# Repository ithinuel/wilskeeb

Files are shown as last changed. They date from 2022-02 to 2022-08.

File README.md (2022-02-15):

# Wil's Keyboard

This project implements a split keyboard based on the [Redox](https://github.com/mattdibi/redox-keyboard)
PCB but powered by a [SparkFun Pro Micro - RP2040](https://www.sparkfun.com/products/18288).

It features:

- Automatic main-secondary detection (either side can be connected to usb)
- Automatic chirality detection allowing the same binary to run on both sides.
- A virtual serial port to a simple CLI to help with debugging & update.
- 128x64 (SH1107 based) Oled display support

Extra optional features are also available:

- RGB Led strip

The communication between main & secondary is done through an I²C interface.

## Firmware deployment

On a fresh RP2040 enter into bootload by maintaining the boot button pressed while pressing reset.
Then run `cargo run --release` to compile and flash the firmware.

Refer to defmt documentation for available logging parameters.

I used the following command to update the firmware after the case is assembled and the buttons are
no-longer accessible.

```sh
DEFMT_BBQ_BUFFER_SIZE=4096 DEFMT_LOG=trace cargo build --release && echo -n u >> [your-uart] && sleep 5 && elf2uf2-rs -d target/thumbv6m-none-eabi/release/wilskeeb
```

## Layout

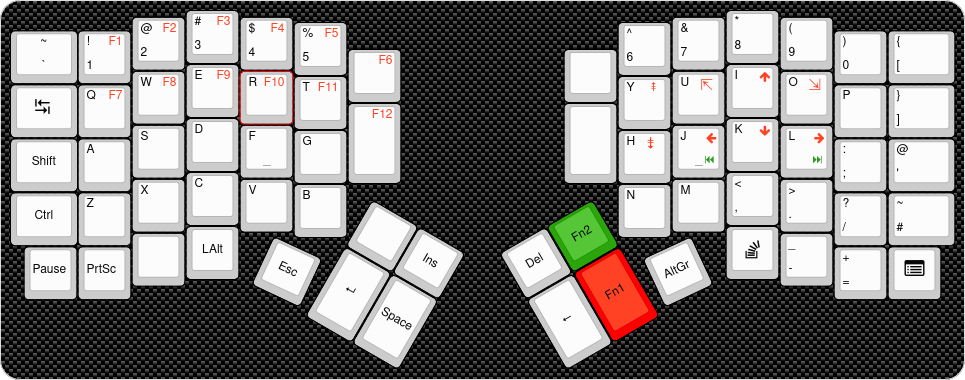
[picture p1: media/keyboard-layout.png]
Keyboard layout
[](http://www.keyboard-layout-editor.com/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(%0A9%3B&@_y:-0.905&x:5.25&t=%23000000%0A%0A%23ff0000%3B&=%25%0A5%0AF5&_x:5&t=%23000000%3B&=%5E%0A6%3B&@_y:-0.845&a:5&w:1.25%3B&=~%0A%60&_t=%23000000%0A%0A%23ff0000&a:4%3B&=!%0A1%0AF1&_x:13&t=%23000000%3B&=)%0A0&_w:1.25%3B&=%7B%0A%5B%3B&@_y:-0.655&x:6.25&t=%23000000%0A%0A%23ff0000%3B&=%0A%0AF6&_x:3&t=%23000000&a:7%3B&=%3B&@_y:-0.72&x:3.25&t=%23000000%0A%0A%23ff0000&a:4%3B&=E%0A%0AF9&_x:9%3B&=I%0A%0A%3Ci%20class%2F='fa%20fa-arrow-up'%3E%3C%2F%2Fi%3E%3B&@_y:-0.875&x:2.25%3B&=W%0A%0AF8&_x:1%3B&=R%0A%0AF10&_x:7&fa@:0&:0&:5%3B%3B&=U%0A%0A%3Ci%20class%2F='kb%20kb-Arrows-Top-2'%3E%3C%2F%2Fi%3E&_x:1%3B&=O%0A%0A%3Ci%20class%2F='kb%20kb-Arrows-Bottom-2'%3E%3C%2F%2Fi%3E%3B&@_y:-0.905&x:5.25&f:3%3B&=T%0A%0AF11&_x:5&f:3%3B&=Y%0A%0A%3Ci%20class%2F='kb%20kb-Unicode-Page-Up-3'%3E%3C%2F%2Fi%3E%3B&@_y:-0.845&t=%23000000&a:7&fa@:7%3B&w:1.25%3B&=%3Ci%20class%2F='kb%20kb-Line-Start-End'%3E%3C%2F%2Fi%3E&_t=%23000000%0A%0A%23ff0000&a:4&f:3%3B&=Q%0A%0AF7%3B&@_y:-1&x:15.25&t=%23000000&f:3%3B&=P&_f:3&w:1.25%3B&=%7D%0A%5D%3B&@_y:-0.655&x:6.25&t=%23000000%0A%0A%23ff0000&h:1.5%3B&=%0A%0AF12&_x:3&t=%23000000&a:7&h:1.5%3B&=%3B&@_y:-0.72&x:3.25&a:4&f:3%3B&=D%3B&@_y:-1&x:13.25&t=%23000000%0A%0A%23ff0000&f:3%3B&=K%0A%0A%3Ci%20class%2F='fa%20fa-arrow-down'%3E%3C%2F%2Fi%3E%3B&@_y:-0.875&x:2.25&t=%23000000&f:3%3B&=S&_x:1&f:3&n:true%3B&=F&_x:7&t=%23000000%0A%0A%23ff0000%0A%23008000&f:3&n:true%3B&=J%0A%0A%3Ci%20class%2F='fa%20fa-arrow-left'%3E%3C%2F%2Fi%3E%0A%3Ci%20class%2F='kb%20kb-Multimedia-Rewind-Start'%3E%3C%2F%2Fi%3E&_x:1&f:3%3B&=L%0A%0A%3Ci%20class%2F='fa%20fa-arrow-right'%3E%3C%2F%2Fi%3E%0A%3Ci%20class%2F='kb%20kb-Multimedia-FastForward-End'%3E%3C%2F%2Fi%3E%3B&@_y:-0.9049999999999998&x:5.25&t=%23000000&f:3%3B&=G&_x:5&t=%23000000%0A%0A%23ff0000&fa@:0&:0&:5%3B%3B&=H%0A%0A%3Ci%20class%2F='kb%20kb-Unicode-Page-Down-3'%3E%3C%2F%2Fi%3E%3B&@_y:-0.8450000000000002&t=%23000000&a:7&w:1.25%3B&=Shift&_a:4%3B&=A&_x:13%3B&=%2F:%0A%2F%3B&_w:1.25%3B&=%2F@%0A'%3B&@_y:-0.375&x:3.25%3B&=C&_x:9%3B&=%3C%0A,%3B&@_y:-0.875&x:2.25%3B&=X&_x:1%3B&=V&_x:7%3B&=M&_x:1%3B&=%3E%0A.%3B&@_y:-0.9049999999999998&x:5.25%3B&=B&_x:5%3B&=N%3B&@_y:-0.8450000000000006&a:7&w:1.25%3B&=Ctrl&_a:4%3B&=Z&_x:13%3B&=%3F%0A%2F%2F&_w:1.25%3B&=~%0A%23%3B&@_y:-0.375&x:3.25&a:7%3B&=LAlt&_x:9&fa@:6%3B%3B&=%3Ci%20class%2F='fa%20fa-stack-overflow'%3E%3C%2F%2Fi%3E%3B&@_y:-0.875&x:2.25%3B&=&_x:11&a:4&f:3%3B&=%2F_%0A-%3B&@_y:-0.75&x:0.25&a:6&f:3%3B&=Pause&_f:3%3B&=PrtSc&_x:13&a:4&f:3%3B&=+%0A%2F=&_a:7&fa@:7%3B%3B&=%3Ci%20class%2F='fa%20fa-list-alt'%3E%3C%2F%2Fi%3E%3B&@_r:25&rx:5.135&ry:4.845&y:-0.5&x:-0.5&f:3%3B&=Esc%3B&@_r:30&rx:7.068&ry:4.875&y:-1&x:-1%3B&=&_f:3%3B&=Ins%3B&@_x:-1&f:3&h:1.5%3B&=%3Ci%20class%2F='kb%20kb-Return-2'%3E%3C%2F%2Fi%3E&_f:3&h:1.5%3B&=Space%3B&@_r:-30&rx:10.432&y:-1&x:-1&f:3%3B&=Del&_c=%232aa50a&f:3%3B&=Fn2%3B&@_x:-1&c=%23cccccc&f:3&h:1.5%3B&=%3Ci%20class%2F='kb%20kb-Arrows-Left'%3E%3C%2F%2Fi%3E&_c=%23ff0000&f:3&h:1.5%3B&=Fn1%3B&@_r:-25&rx:12.365&ry:4.845&y:-0.5&x:-0.5&c=%23cccccc&f:3%3B&=AltGr)

## Licenses

The hardware design files present in this repository under the `pcb` and `case` directories are
distributed under the [CERN OHL S v2 License](./cern_ohl_s_v2.txt).

```text
Copyright Wilfried Chauveau 2022.

This source describes Open Hardware and is licensed under the CERN-OHL-S v2.
You may redistribute and modify this source and make products using it under
the terms of the CERN-OHL-S v2 (https://ohwr.org/cern_ohl_s_v2.txt).

This source is distributed WITHOUT ANY EXPRESS OR IMPLIED WARRANTY, INCLUDING
OF MERCHANTABILITY, SATISFACTORY QUALITY AND FITNESS FOR A PARTICULAR PURPOSE.
Please see the CERN-OHL-S v2 for applicable conditions.

Source location: https://github.com/ithinuel/wilskeeb.git

As per CERN-OHL-S v2 section 4, should You produce hardware based on this source,
You must where practicable maintain the Source Location visible on the external
case of the Gizmo or other products you make using this source.
```

The sources available under the `firmware` directory are distributed under the
[Apache 2](./Apache-2.0.txt) license.

```text
Copyright 2022 Wilfried Chauveau

Licensed under the Apache License, Version 2.0 (the "License");
you may not use this file except in compliance with the License.
You may obtain a copy of the License at

    http://www.apache.org/licenses/LICENSE-2.0

Unless required by applicable law or agreed to in writing, software
distributed under the License is distributed on an "AS IS" BASIS,
WITHOUT WARRANTIES OR CONDITIONS OF ANY KIND, either express or implied.
See the License for the specific language governing permissions and
limitations under the License.
```

## Extra resources

- The 3D model for the Audio jack is available at : [Kicad-packages3D − MR#495](https://gitlab.com/kicad/libraries/kicad-packages3D/-/merge_requests/495)
- The PCB design for the OLED display can be found at : [Github − Adafruit OLED FeatherWing PCB](https://github.com/adafruit/Adafruit-OLED-FeatherWing-PCB.git)
- The PCB design for the Pro Micro RP2040 can be found at : [Github − SparkFun Pro Micro RP2040](https://github.com/sparkfun/SparkFun_Pro_Micro-RP2040.git)

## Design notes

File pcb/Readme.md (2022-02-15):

# PCD Design

## Option considered

- on board per key rgb LED using WS2812-2020  
  Those RGB LED draw up to 20mA and there would be 35 of them. This plus the rest of the system would
  exceed the capacity of the USB port.

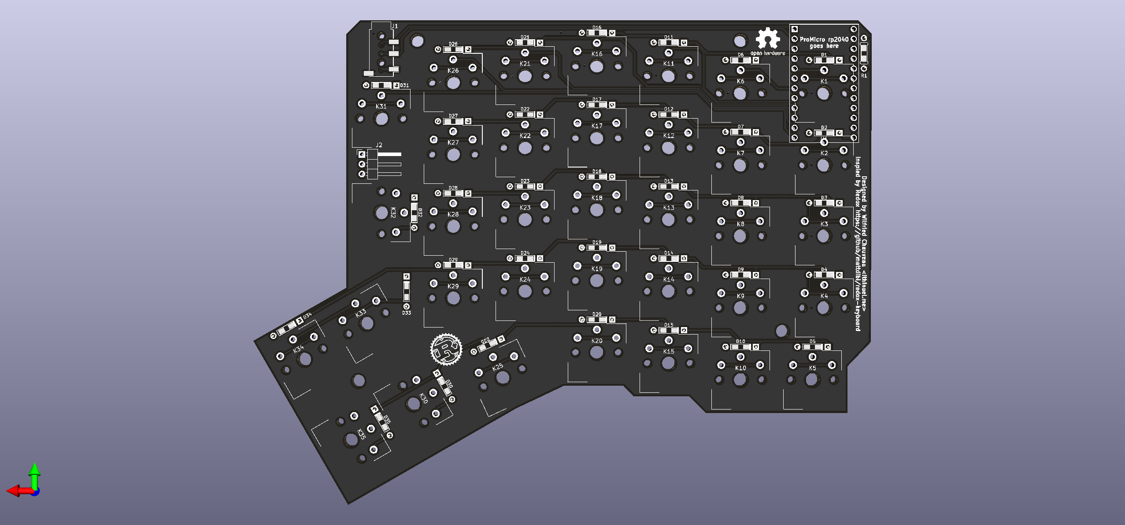
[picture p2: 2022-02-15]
media/wilskeeb_6.png

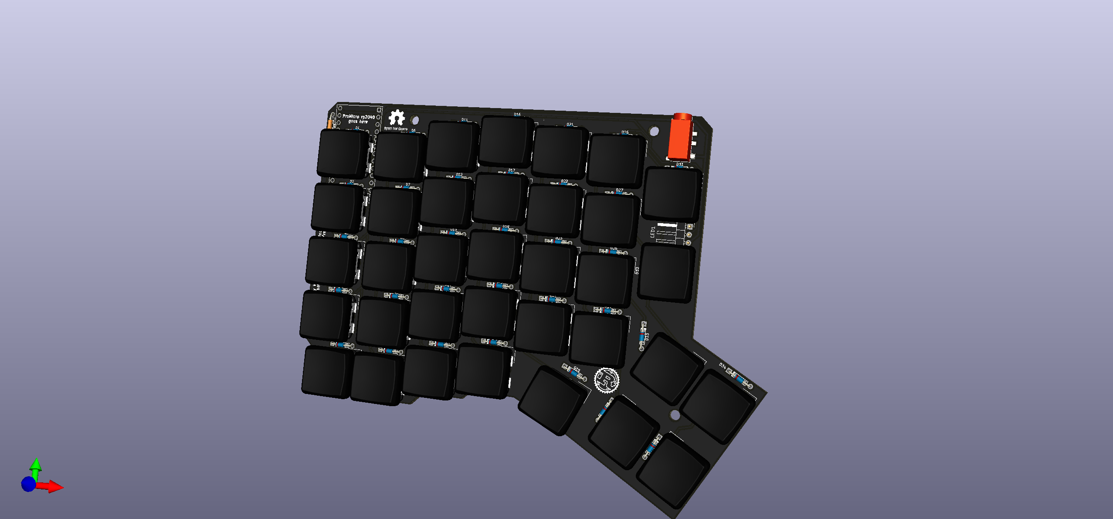
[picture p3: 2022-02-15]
media/wilskeeb_1.png

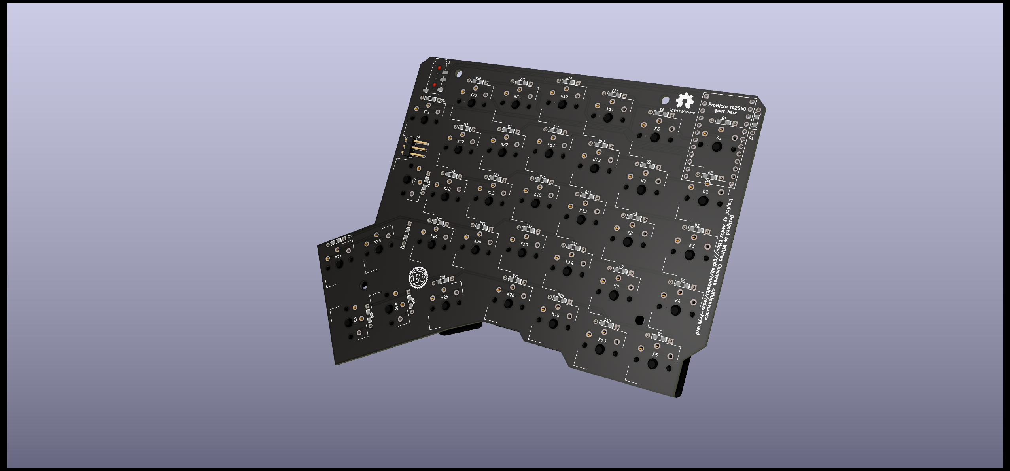
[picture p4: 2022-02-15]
media/wilskeeb_raytraced_back.png

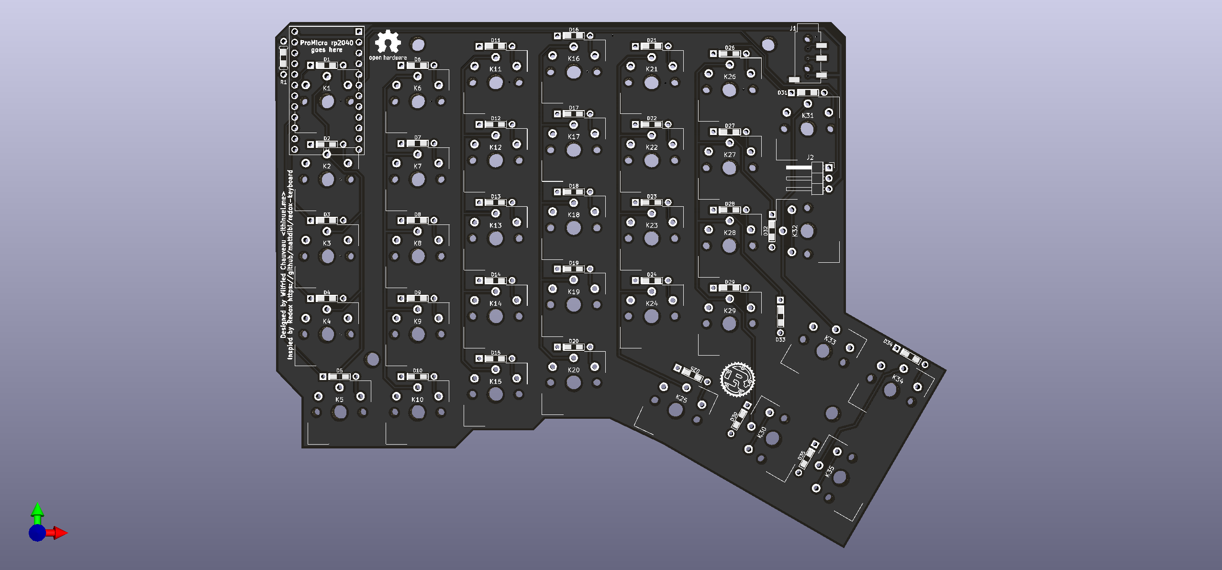
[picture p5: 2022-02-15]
media/wilskeeb_left.png

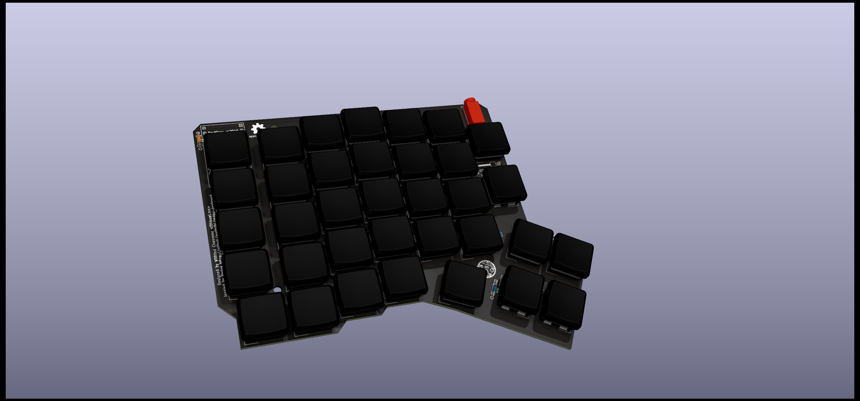
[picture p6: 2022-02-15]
media/wilskeeb_3.png

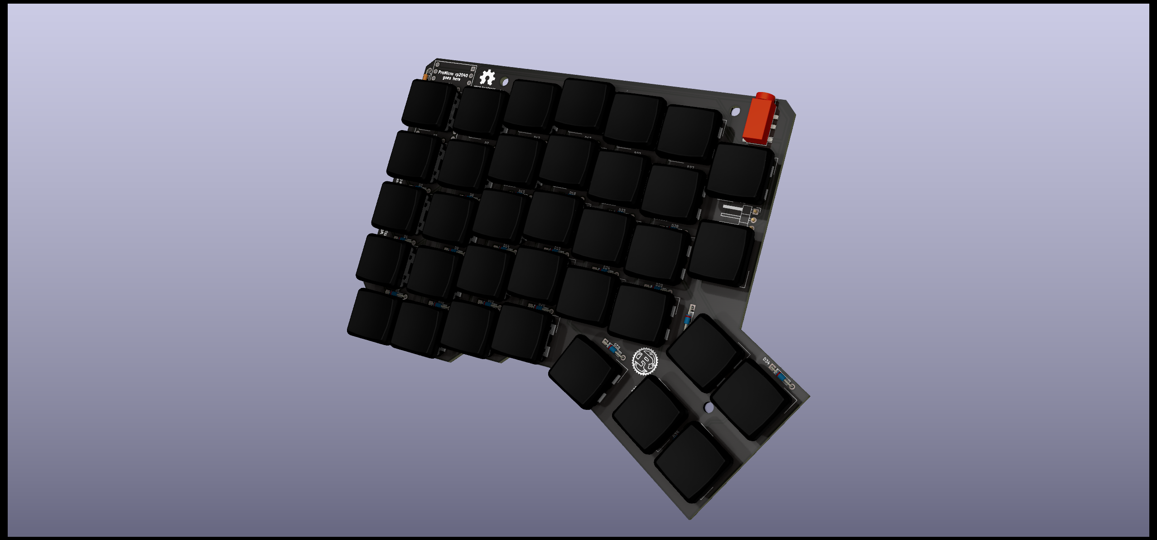
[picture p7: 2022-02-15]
media/wilskeeb_raytraced_front.png

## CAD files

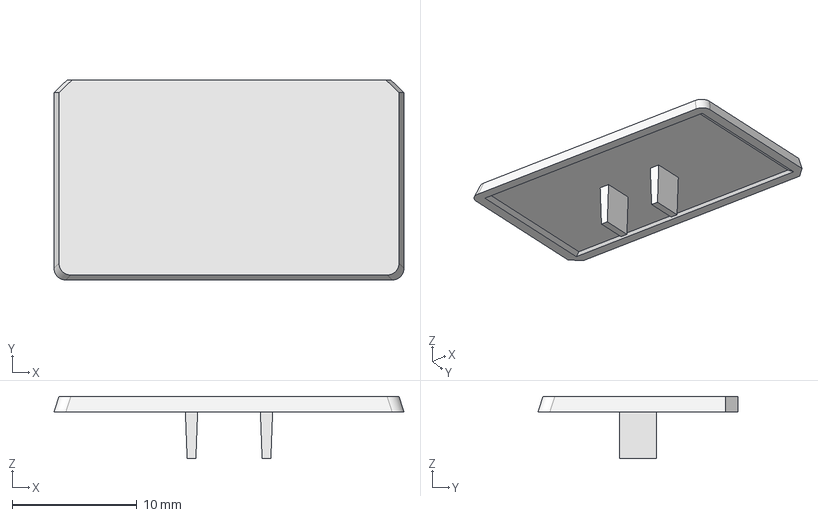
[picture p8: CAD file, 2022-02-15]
case/kailh_keycap.FCStd
28.0 x 16.0 x 5.00 mm

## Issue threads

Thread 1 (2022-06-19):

TRRS connector too far back

ithinuel, 2022-06-19:
The TRRS jack connector is a bit too far back preventing the cable to fully insert.

In some cases it may prevent the cable to securely attach and cause disruption of the link.

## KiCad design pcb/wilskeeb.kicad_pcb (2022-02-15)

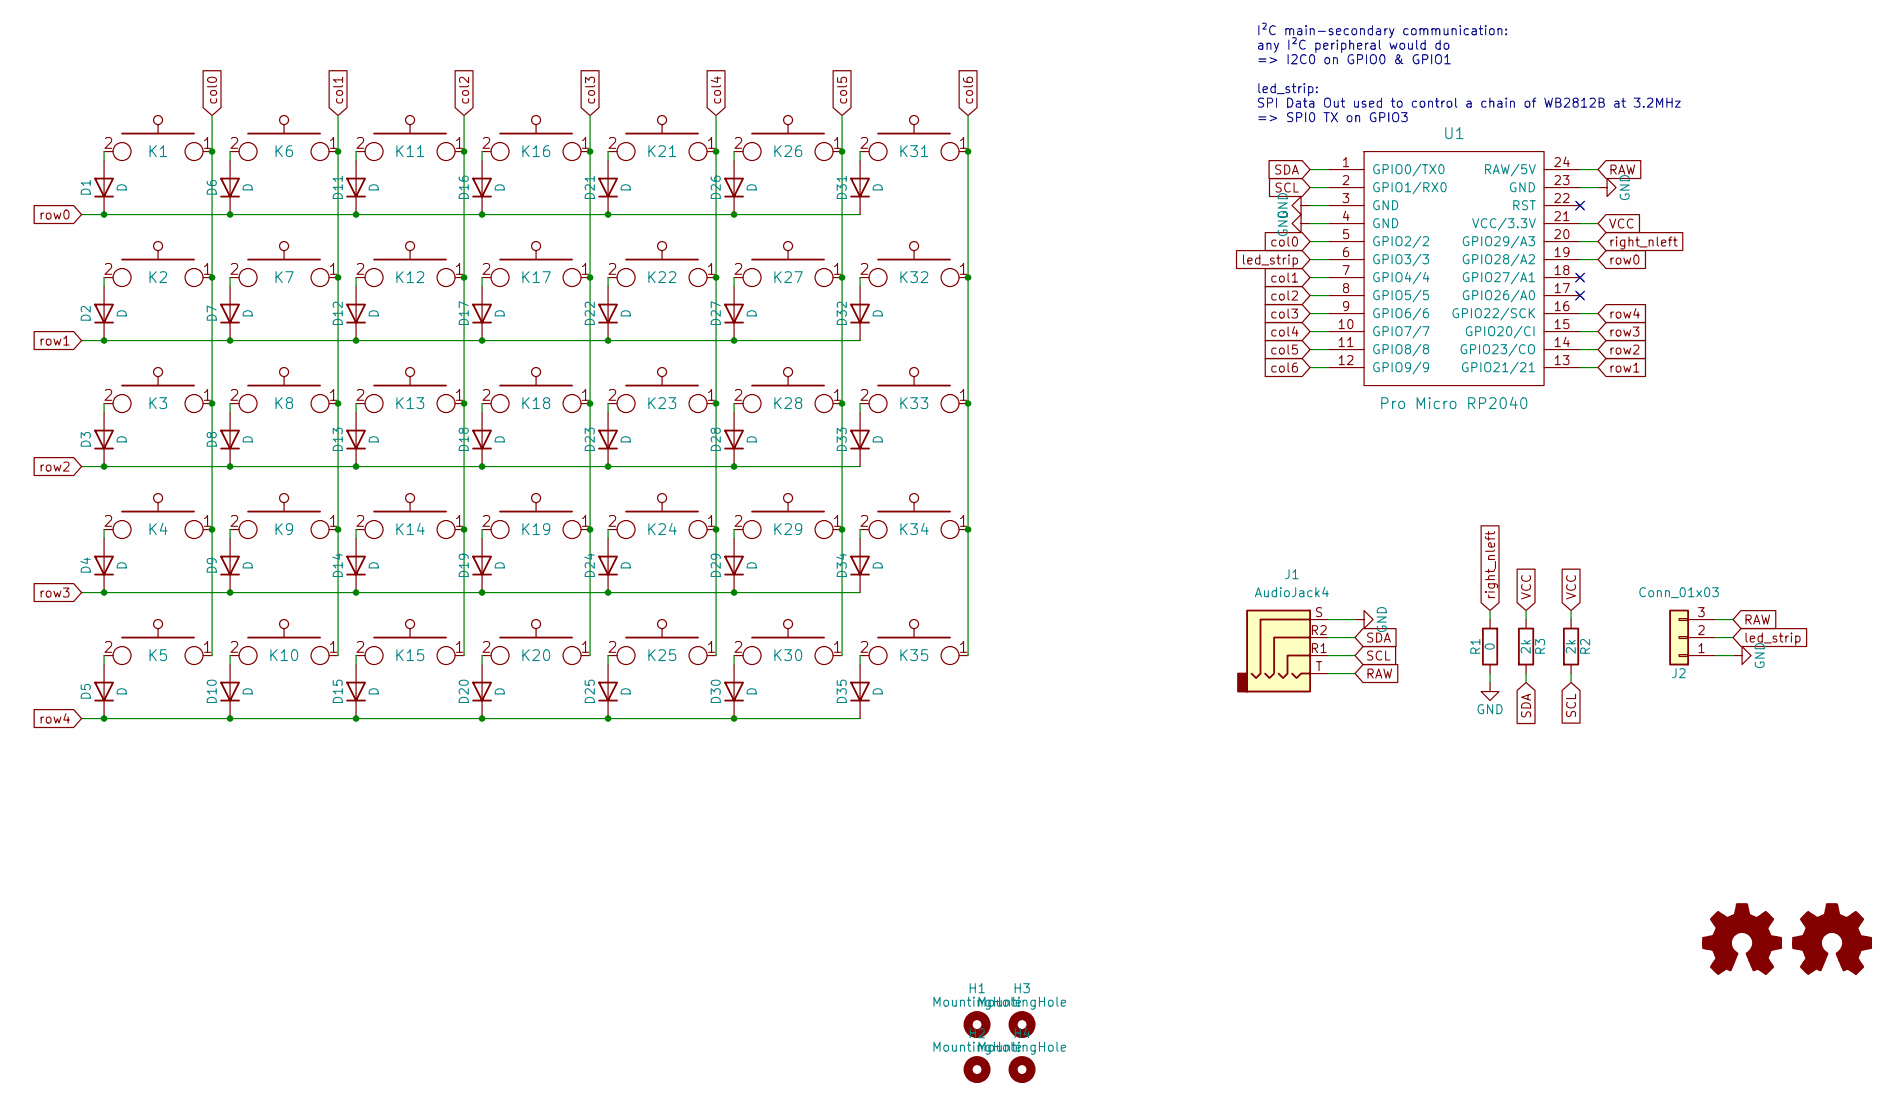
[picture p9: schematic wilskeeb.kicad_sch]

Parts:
D1, D2, D3, D4, D5, D6, D7, D8, D9, D10, D11, D12, D13, D14, D15, D16, D17, D18, D19, D20, D21, D22, D23, D24, D25, D26, D27, D28, D29, D30, D31, D32, D33, D34, D35: D; Diode-Hybrid-Reversible
H1, H2, H3, H4: MountingHole; MountingHole_3.2mm_M3_ISO14580
J1: AudioJack4; Jack_3.5mm_TRRS_PJ320D_Reversible
J2: Conn_01x03; PinHeader_1x03_P2.54mm_Horizontal
K1, K2, K3, K4, K5, K6, K7, K8, K9, K10, K11, K12, K13, K14, K15, K16, K17, K18, K19, K20, K21, K22, K23, K24, K25, K26, K27, K28, K29, K30, K31, K32, K33, K34, K35: KEYSW; PG1350-1u-Reversible
R1: 0; Resistor-Hybrid-Reversible
R2, R3: 2k; Resistor-Hybrid-Reversible
U1: Pro Micro RP2040; ProMicro-Reversible

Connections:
GND: J1.S, J2.1, R1.1, U1.3 (GND), U1.4 (GND), U1.23 (GND)
unnamed: D1.2 (A), K1.2
unnamed: D2.2 (A), K2.2
unnamed: D3.2 (A), K3.2
unnamed: D4.2 (A), K4.2
unnamed: D5.2 (A), K5.2
unnamed: D6.2 (A), K6.2
unnamed: D7.2 (A), K7.2
unnamed: D8.2 (A), K8.2
unnamed: D9.2 (A), K9.2
unnamed: D10.2 (A), K10.2
unnamed: D11.2 (A), K11.2
unnamed: D12.2 (A), K12.2
unnamed: D13.2 (A), K13.2
unnamed: D14.2 (A), K14.2
unnamed: D15.2 (A), K15.2
unnamed: D16.2 (A), K16.2
unnamed: D17.2 (A), K17.2
unnamed: D18.2 (A), K18.2
unnamed: D19.2 (A), K19.2
unnamed: D20.2 (A), K20.2
unnamed: D21.2 (A), K21.2
unnamed: D22.2 (A), K22.2
unnamed: D23.2 (A), K23.2
unnamed: D24.2 (A), K24.2
unnamed: D25.2 (A), K25.2
unnamed: D26.2 (A), K26.2
unnamed: D27.2 (A), K27.2
unnamed: D28.2 (A), K28.2
unnamed: D29.2 (A), K29.2
unnamed: D30.2 (A), K30.2
unnamed: D31.2 (A), K31.2
unnamed: D32.2 (A), K32.2
unnamed: D33.2 (A), K33.2
unnamed: D34.2 (A), K34.2
unnamed: D35.2 (A), K35.2
RAW: J1.T, J2.3, U1.24 (RAW/5V)
SCL: J1.R1, R2.2, U1.2 (GPIO1/RX0)
SDA: J1.R2, R3.2, U1.1 (GPIO0/TX0)
VCC: R2.1, R3.1, U1.21 (VCC/3.3V)
col0: K1.1, K2.1, K3.1, K4.1, K5.1, U1.5 (GPIO2/2)
col1: K6.1, K7.1, K8.1, K9.1, K10.1, U1.7 (GPIO4/4)
col2: K11.1, K12.1, K13.1, K14.1, K15.1, U1.8 (GPIO5/5)
col3: K16.1, K17.1, K18.1, K19.1, K20.1, U1.9 (GPIO6/6)
col4: K21.1, K22.1, K23.1, K24.1, K25.1, U1.10 (GPIO7/7)
col5: K26.1, K27.1, K28.1, K29.1, K30.1, U1.11 (GPIO8/8)
col6: K31.1, K32.1, K33.1, K34.1, K35.1, U1.12 (GPIO9/9)
led_strip: J2.2, U1.6 (GPIO3/3)
right_nleft: R1.2, U1.20 (GPIO29/A3)
row0: D1.1 (K), D6.1 (K), D11.1 (K), D16.1 (K), D21.1 (K), D26.1 (K), D31.1 (K), U1.19 (GPIO28/A2)
row1: D2.1 (K), D7.1 (K), D12.1 (K), D17.1 (K), D22.1 (K), D27.1 (K), D32.1 (K), U1.13 (GPIO21/21)
row2: D3.1 (K), D8.1 (K), D13.1 (K), D18.1 (K), D23.1 (K), D28.1 (K), D33.1 (K), U1.14 (GPIO23/CO)
row3: D4.1 (K), D9.1 (K), D14.1 (K), D19.1 (K), D24.1 (K), D29.1 (K), D34.1 (K), U1.15 (GPIO20/CI)
row4: D5.1 (K), D10.1 (K), D15.1 (K), D20.1 (K), D25.1 (K), D30.1 (K), D35.1 (K), U1.16 (GPIO22/SCK)

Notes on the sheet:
I²C main-secondary communication: any I²C peripheral would do => I2C0 on GPIO0 & GPIO1 led_strip: SPI Data Out used to control a chain of WB2812B at 3.2MHz => SPI0 TX on GPIO3

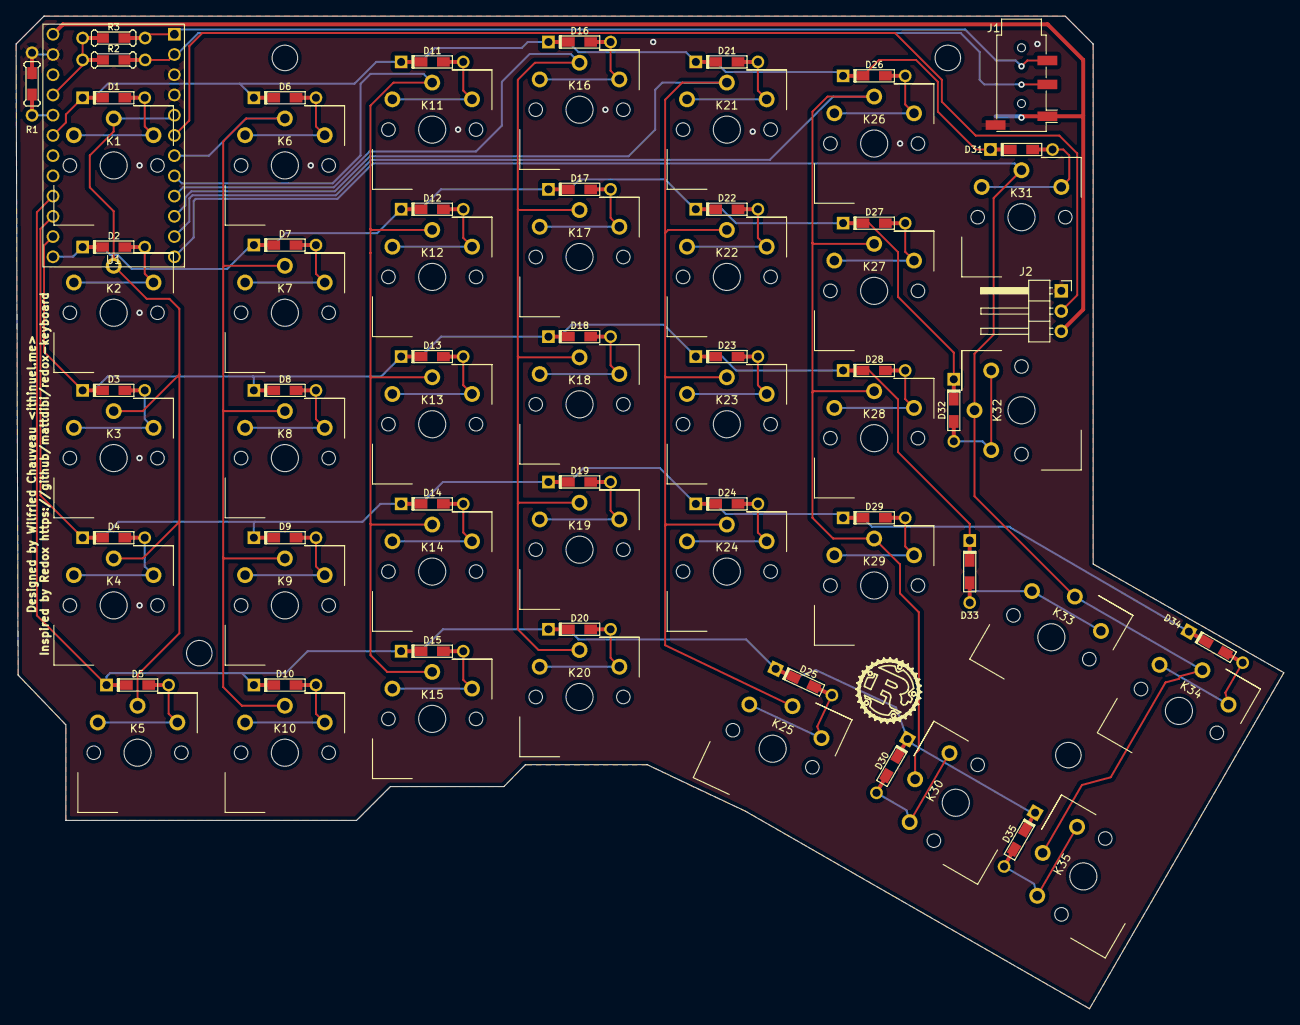
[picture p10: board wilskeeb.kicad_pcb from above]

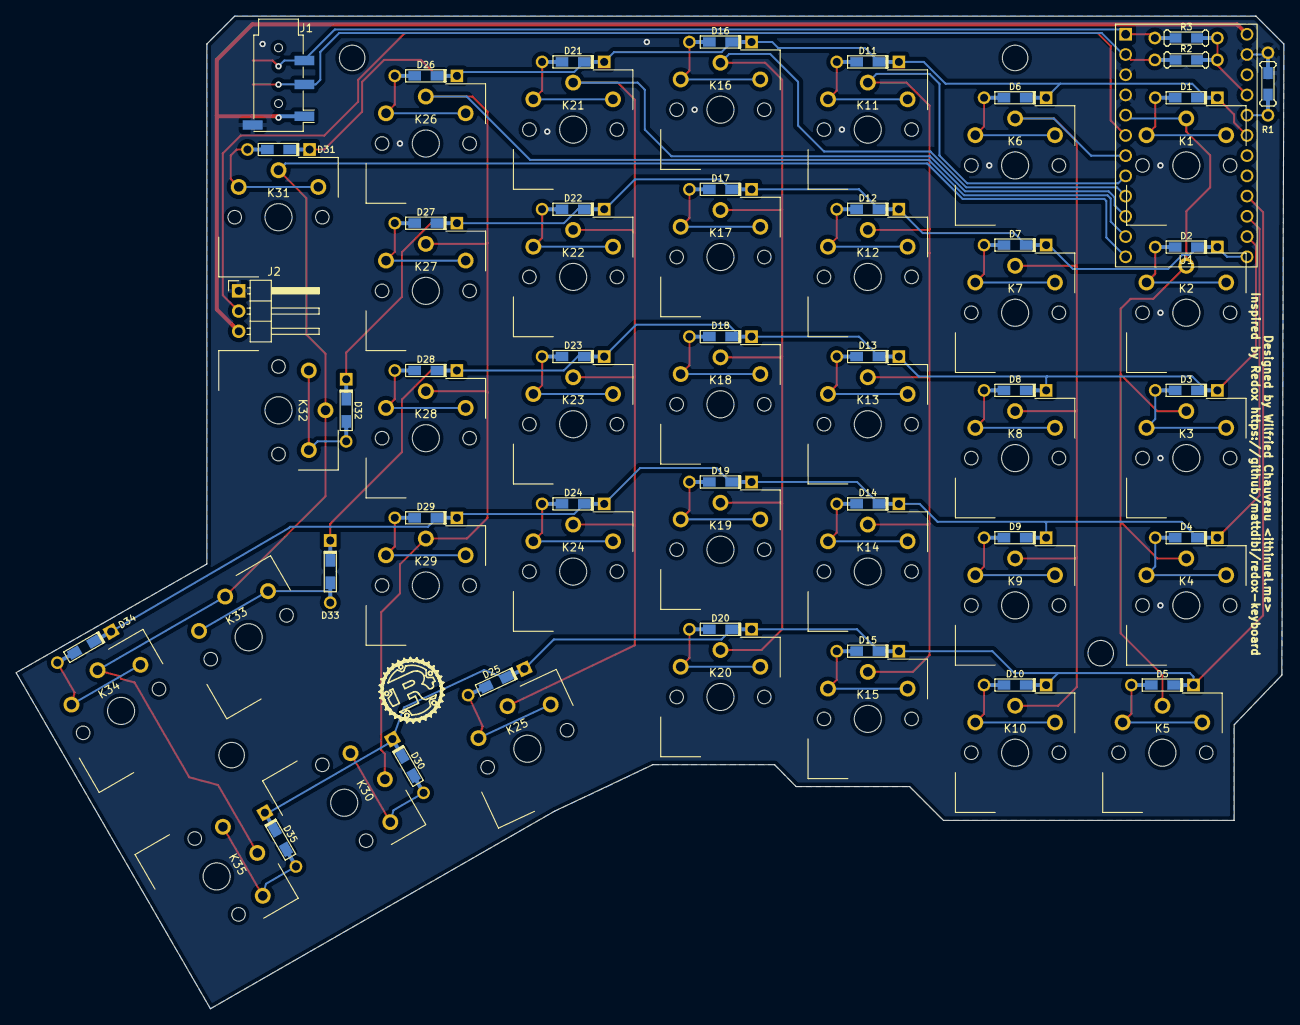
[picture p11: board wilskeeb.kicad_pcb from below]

Board: 2 copper layers, 159.2 x 124.7 mm, 80 parts (2 on the bottom side), 54 nets.

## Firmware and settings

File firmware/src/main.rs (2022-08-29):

#![doc = include_str!("../../README.md")]
#![no_std]
#![no_main]
#![feature(type_alias_impl_trait)]

#[cfg(any(
    all(feature = "debug-to-probe", feature = "debug-to-cli"),
    all(
        feature = "debug",
        not(any(feature = "debug-to-probe", feature = "debug-to-cli"))
    )
))]
compile_error!(
    "Only one feature of \"debug-to-probe\" or \"debug-to-cli\" must be enabled for this create"
);

use core::{
    cell::RefCell,
    iter::once,
    sync::atomic::{AtomicBool, AtomicU8, Ordering},
};

#[cfg(feature = "debug-to-probe")]
use panic_probe as _;
#[cfg(not(any(feature = "debug-to-probe", feature = "debug-to-cli")))]
use panic_reset as _;

#[cfg(feature = "debug-to-probe")]
use defmt_rtt as _;

use fugit::{ExtU32, HertzU32, MicrosDurationU32, RateExtU32, TimerInstantU64};

use rp2040_hal::{
    gpio::{bank0, Pin, Pins, PullDownDisabled},
    pac,
    pio::{self, PIOExt},
    sio::Sio,
    timer::Timer,
    usb::UsbBus,
    watchdog::Watchdog,
    Clock,
};

use frunk::hlist::{HCons, HNil};
use usb_device::{
    bus::UsbBusAllocator,
    class::UsbClass as _,
    device::{UsbDeviceBuilder, UsbDeviceState, UsbVidPid},
};
use usbd_human_interface_device::{
    device::keyboard::NKROBootKeyboardInterface,
    hid_class::{UsbHidClass, UsbHidClassBuilder},
    page::Keyboard,
    UsbHidError,
};
#[cfg(feature = "cli")]
use usbd_serial::SerialPort;

use arraydeque::{behavior::Saturating, ArrayDeque};
use arrayvec::ArrayVec;
use keyberon::{
    debounce::Debouncer,
    layout::{CustomEvent, Event, Layout},
};
use num_enum::FromPrimitive;
use smart_leds::{brightness, SmartLedsWrite, RGB8};

#[cfg(not(feature = "debug"))]
mod defmt {
    #[macro_export]
    macro_rules! trace {
        ($($_:tt)*) => {{}};
    }
    #[macro_export]
    macro_rules! debug {
        ($($_:tt)*) => {{}};
    }
    #[macro_export]
    macro_rules! info {
        ($($_:tt)*) => {{}};
    }
    #[macro_export]
    macro_rules! error {
        ($($_:tt)*) => {{}};
    }
    #[macro_export]
    macro_rules! timestamp {
        ($($_:tt)*) => {};
    }

    // macros are exported at the root of the crate so pull them back here
    pub use super::{debug, error, info, timestamp, trace};
}

#[cfg(feature = "cli")]
mod cli;
mod inter_board;
mod layout;
mod matrix;
//mod ui;
mod utils_async;
mod utils_time;

use layout::CustomAction;
use utils_time::MyClock;

#[derive(Debug, Clone, Copy, PartialEq, Eq)]
#[cfg_attr(feature = "debug", derive(defmt::Format))]
pub enum Source {
    Left,
    Right,
}
impl core::ops::Not for Source {
    type Output = Source;

    fn not(self) -> Self::Output {
        match self {
            Source::Left => Source::Right,
            Source::Right => Source::Left,
        }
    }
}

const SCANNED_STACK_SZ: usize = 16;
const TO_USB_STACK_SZ: usize = 32;

type ScannedEventStack = ArrayDeque<[Event; SCANNED_STACK_SZ], Saturating>;
type ToUSBStack = ArrayDeque<[(Source, Event); TO_USB_STACK_SZ], Saturating>;
type InterfaceList<'a> = HCons<NKROBootKeyboardInterface<'a, UsbBus, MyClock<'a>>, HNil>;
type MyUsbHidClass<'a> = UsbHidClass<UsbBus, InterfaceList<'a>>;
#[cfg(feature = "cli")]
type UsbSerialCell<'a> =
    RefCell<SerialPort<'a, UsbBus, [u8; USB_SERIAL_RX_SZ], [u8; USB_SERIAL_TX_SZ]>>;
type TimerInstant = TimerInstantU64<1_000_000>;

struct BlackBoard {
    /// The use of that field is a bit ugly but `UsbDeviceState` is `repr(u8)` so it should be ok.
    usb_state: AtomicU8,
    is_main_half: AtomicBool,
    scanned: RefCell<ScannedEventStack>,
    to_usb: RefCell<ToUSBStack>,
}

/// USB VID/PID for a generic keyboard from <https://github.com/obdev/v-usb/blob/master/usbdrv/USB-IDs-for-free.txt>
const VID_PID: UsbVidPid = UsbVidPid(0x16c0, 0x27db);
const DEVICE_RELEASE: u16 = 0x0100;
/// USB Serial cli update frequency.
#[cfg(feature = "cli")]
const CLI_FREQUENCY: HertzU32 = HertzU32::kHz(1);
/// Matrix scan frequency.
const SCAN_FREQUENCY: HertzU32 = HertzU32::kHz(5);
/// Time required for a key press to stop bouncing.
const DEBOUNCE_PERIOD: MicrosDurationU32 = MicrosDurationU32::millis(5);
/// Maximum async task count on the system
#[cfg(feature = "cli")]
const TASK_COUNT: usize = 5;
#[cfg(not(feature = "cli"))]
const TASK_COUNT: usize = 6;

static_assertions::const_assert!(DEBOUNCE_PERIOD.ticks() <= (u16::max_value() as u32));
static_assertions::const_assert!(matches!(
    DEBOUNCE_PERIOD.const_partial_cmp(SCAN_FREQUENCY.into_duration::<1, 1_000_000>()),
    Some(core::cmp::Ordering::Greater | core::cmp::Ordering::Equal)
));

#[cfg(feature = "cli")]
const USB_SERIAL_RX_SZ: usize = 64;
#[cfg(feature = "cli")]
const USB_SERIAL_TX_SZ: usize = 1024;

static IS_RIGHT: AtomicBool = AtomicBool::new(false);

defmt::timestamp!("{=u32:us}", {
    // NOTE(interrupt-safe) single instruction volatile read operation
    unsafe { pac::Peripherals::steal().TIMER.timerawl.read().bits() }
});

/// Detects which keyboard half we are running.
fn read_side() -> Source {
    if IS_RIGHT.load(Ordering::Relaxed) {
        Source::Right
    } else {
        Source::Left
    }
}

/// Key board scan task
///
/// Handles:
/// - Scans the matrix
/// - Debounces matrix' state
/// - Stacks the events on the blackboard
async fn scan_app(board: &BlackBoard, timer: &Timer, mut matrix: matrix::Matrix) {
    const SCAN_PERIOD: MicrosDurationU32 = SCAN_FREQUENCY.into_duration();
    const DEBOUNCE_TICKS: u16 = (DEBOUNCE_PERIOD.ticks() / SCAN_PERIOD.ticks()) as u16;

    let BlackBoard { scanned, .. } = board;

    let mut debouncer = Debouncer::new(Default::default(), Default::default(), DEBOUNCE_TICKS);

    let mut now = timer.get_counter();
    loop {
        now = utils_async::wait_until(timer, now + SCAN_PERIOD).await;
        let mut scanned = scanned.borrow_mut();
        for event in debouncer.events(matrix.get()) {
            // TODO: if for some reason the queue isn't processed.
            // shall we drop the oldest or ignore the most recent?

            defmt::info!(" Scan: {}", inter_board::EventWrapper(event));
            let _ = scanned.push_back(event);
        }
        drop(scanned);
    }
}

/// Inter-Keyboard half communication task
///
/// Handles:
/// - negociation of main/secondary keyboard half
/// - when acting as main:
///   - reads events from secondary and stacks them on the blackboard;
///   - sends ui updates;
/// - when acting as secondary: serves requests comming from main.
async fn inter_board_app(
    board: &BlackBoard,
    system_clock: &rp2040_hal::clocks::SystemClock,
    i2c_block: pac::I2C0,
    sda: Pin<bank0::Gpio0, PullDownDisabled>,
    scl: Pin<bank0::Gpio1, PullDownDisabled>,
    resets: pac::RESETS,
    timer: &Timer,
) {
    let BlackBoard {
        usb_state,
        scanned,
        to_usb,
        is_main_half,
        ..
    } = board;

    let (mut sda, mut scl) = (sda.into_mode(), scl.into_mode());
    scl.set_slew_rate(rp2040_hal::gpio::OutputSlewRate::Slow);
    sda.set_slew_rate(rp2040_hal::gpio::OutputSlewRate::Slow);
    // Fix odd capacitor-like signal behavior
    scl.set_drive_strength(rp2040_hal::gpio::OutputDriveStrength::TwoMilliAmps);
    sda.set_drive_strength(rp2040_hal::gpio::OutputDriveStrength::TwoMilliAmps);

    let mut inter_board = inter_board::InterBoard::new(
        system_clock,
        i2c_block,
        (sda, scl),
        resets,
        timer.get_counter(),
    );

    // wait for usb configured state or an i2c sync packet
    loop {
        let usb_state = unsafe { core::mem::transmute(usb_state.load(Ordering::Relaxed)) };
        inter_board = inter_board.poll(usb_state, timer, scanned, to_usb).await;

        is_main_half.store(inter_board.is_main(), Ordering::Relaxed);
    }
}

/// USB polling task
///
/// Handles:
/// - Processing the usb stack and associated protocols.
/// - Draining the keyboard event stack from the blackboard and feeds it into the layout
/// - Ticks the layout & generates HID reports
async fn usb_app<'a>(
    board: &BlackBoard,
    timer: &Timer,
    usb_bus: &UsbBusAllocator<UsbBus>,
    mut keyboard_hid: MyUsbHidClass<'_>,
    #[cfg(feature = "cli")] usb_serial: &UsbSerialCell<'a>,
) {
    let BlackBoard {
        to_usb,
        is_main_half,
        ..
    } = board;
    let builder = UsbDeviceBuilder::new(usb_bus, VID_PID)
        .manufacturer("Ithinuel.me")
        .product("WilsKeeb")
        .serial_number("Dev Environment")
        .supports_remote_wakeup(true)
        .device_class(0)
        .device_sub_class(0)
        .device_protocol(0)
        .max_packet_size_0(64)
        .max_power(500)
        .device_release(DEVICE_RELEASE);
    #[cfg(feature = "cli")]
    let builder = builder.composite_with_iads();
    let mut usb_dev = builder.build();

    let mut layout = Layout::new(&layout::LAYERS);
    let mut timestamp = timer.get_counter_low();
    loop {
        utils_async::wait_for(timer, 10.micros()).await;

        #[cfg(feature = "cli")]
        if let Ok(mut usb_serial) = usb_serial.try_borrow_mut() {
            if usb_dev.poll(&mut [&mut keyboard_hid, &mut *usb_serial]) {
                keyboard_hid.poll();
                usb_serial.poll();
            }
        }
        #[cfg(not(feature = "cli"))]
        if usb_dev.poll(&mut [&mut keyboard_hid]) {
            keyboard_hid.poll();
        }

        let usb_state = usb_dev.state();
        board.usb_state.store(usb_state as u8, Ordering::Relaxed);

        let _ = keyboard_hid.interface().read_report();

        // if 1ms since last update
        let now = timer.get_counter_low();

        if is_main_half.load(Ordering::Relaxed) && now.wrapping_sub(timestamp) >= 1_000 {
            timestamp = now;

            // Process events from keypress
            for (source, mut event) in to_usb.borrow_mut().drain(..) {
                if source == Source::Right {
                    event = event.transform(|row, col| (row, 13 - col));
                }
                layout.event(event);
            }
            if let CustomEvent::Press(CustomAction::Bootldr) = layout.tick() {
                rp2040_hal::rom_data::reset_to_usb_boot(0, 0)
            }

            // Collect key presses.
            let keycodes: ArrayVec<_, 70> = layout
                .keycodes()
                .map(|k| Keyboard::from_primitive(k as u8))
                .collect();

            // Setup the report for the control channel
            match keyboard_hid.interface().write_report(&keycodes) {
                Err(UsbHidError::WouldBlock) | Err(UsbHidError::Duplicate) | Ok(_) => {}
                Err(e) => panic!("Failed to write keyboard report: {:?}", e),
            }
            match keyboard_hid.interface().tick() {
                Err(UsbHidError::WouldBlock) | Ok(_) => {}
                Err(e) => panic!("Failed to process keyboard tick: {:?}", e),
            }

            // Wake the host.
            if !keycodes.is_empty()
                && usb_state == UsbDeviceState::Suspend
                && usb_dev.remote_wakeup_enabled()
            {
                usb_dev.bus().remote_wakeup();
            }
        }
    }
}

/// CLI task
///
/// Handles simple request from the usb-serial interface to help manage and debug the firmware.
/// see [`cli::update`] for a full description of the supported commands.
#[cfg(feature = "debug-to-cli")]
async fn cli_app<'a>(
    timer: &Timer,
    usb_serial: &UsbSerialCell<'a>,
    mut consumer: defmt_bbq::DefmtConsumer,
) {
    const CLI_PERIOD: MicrosDurationU32 = CLI_FREQUENCY.into_duration();

    let mut next_scan_at = timer.get_counter() + CLI_PERIOD;
    loop {
        next_scan_at = utils_async::wait_until(timer, next_scan_at).await + CLI_PERIOD;

        cli::update(usb_serial, &mut consumer);
    }
}
#[cfg(all(feature = "cli", not(feature = "debug-to-cli")))]
async fn cli_app<'a>(timer: &Timer, usb_serial: &UsbSerialCell<'a>) {
    const CLI_PERIOD: MicrosDurationU32 = CLI_FREQUENCY.into_duration();

    let mut next_scan_at = timer.get_counter() + CLI_PERIOD;
    loop {
        next_scan_at = utils_async::wait_until(timer, next_scan_at).await + CLI_PERIOD;

        cli::update(usb_serial);
    }
}

/// User Interface task
///
/// Handles:
/// - On pro-micro board's neopixel
/// - LED1 neopixel strip
/// - OLED Display
///
/// Reads status from the black board & updates the UI accordingly.
#[allow(clippy::type_complexity)]
async fn ui_app(
    _board: &BlackBoard,
    timer: &Timer,
    leds: (
        pio::PIO<pac::PIO0>,
        pio::UninitStateMachine<pio::PIO0SM0>,
        Pin<bank0::Gpio25, PullDownDisabled>,
        pio::UninitStateMachine<pio::PIO0SM1>,
        Pin<bank0::Gpio3, PullDownDisabled>,
    ),
    oled: (
        pio::PIO<pac::PIO1>,
        pio::UninitStateMachine<pio::PIO1SM0>,
        Pin<bank0::Gpio16, PullDownDisabled>,
        Pin<bank0::Gpio17, PullDownDisabled>,
    ),
    system_clock: &rp2040_hal::clocks::SystemClock,
) {
    let (mut pio0, pio0sm0, sda, scl) = oled;
    let _oled_display = i2c_pio::I2C::new(
        &mut pio0,
        sda.into_pull_up_disabled(),
        scl.into_pull_up_disabled(),
        pio0sm0,
        400_000.Hz(),
        system_clock.freq(),
    );
    let (mut pio1, pio1sm0, neopixel, pio1sm1, strip) = leds;
    let mut neopixel = ws2812_pio::Ws2812::new(
        neopixel.into_mode(),
        &mut pio1,
        pio1sm0,
        system_clock.freq(),
        timer.count_down(),
    );
    let _led_strip = ws2812_pio::Ws2812::new(
        strip.into_mode(),
        &mut pio1,
        pio1sm1,
        system_clock.freq(),
        timer.count_down(),
    );
    let mut timestamp = timer.get_counter();
    for wheel_pos in (0..=255).cycle() {
        defmt::info!("ui task heart beat");
        timestamp = utils_async::wait_until(timer, timestamp + 40_000.micros()).await;

        neopixel
            .write(brightness(once(wheel(wheel_pos)), 25))
            .expect("Failed to set neopixel's color");
    }
}

/// Convert a number from `0..=255` to an RGB color triplet.
///
/// The colours are a transition from red, to green, to blue and back to red.
fn wheel(mut wheel_pos: u8) -> RGB8 {
    wheel_pos = 255 - wheel_pos;
    if wheel_pos < 85 {
        // No green in this sector - red and blue only
        (255 - (wheel_pos * 3), 0, wheel_pos * 3).into()
    } else if wheel_pos < 170 {
        // No red in this sector - green and blue only
        wheel_pos -= 85;
        (0, wheel_pos * 3, 255 - (wheel_pos * 3)).into()
    } else {
        // No blue in this sector - red and green only
        wheel_pos -= 170;
        (wheel_pos * 3, 255 - (wheel_pos * 3), 0).into()
    }
}

#[sparkfun_pro_micro_rp2040::entry]
fn main() -> ! {
    let mut pac = pac::Peripherals::take().unwrap();
    let _core = pac::CorePeripherals::take().unwrap();
    let mut watchdog = Watchdog::new(pac.WATCHDOG);
    let sio = Sio::new(pac.SIO);

    // External high-speed crystal on the pico board is 12Mhz
    //pac.CLOCKS.sleep_en0.modify(|_, w| {
    //    w.clk_sys_pio0()
    //        .set_bit()
    //        .clk_sys_pio1()
    //        .set_bit()
    //        .clk_sys_jtag()
    //        .set_bit()
    //        .clk_sys_pll_usb()
    //        .set_bit()
    //        .clk_sys_i2c0()
    //        .set_bit()
    //});
    let clocks = rp2040_hal::clocks::init_clocks_and_plls(
        sparkfun_pro_micro_rp2040::XOSC_CRYSTAL_FREQ,
        pac.XOSC,
        pac.CLOCKS,
        pac.PLL_SYS,
        pac.PLL_USB,
        &mut pac.RESETS,
        &mut watchdog,
    )
    .ok()
    .unwrap();

    let pins = Pins::new(
        pac.IO_BANK0,
        pac.PADS_BANK0,
        sio.gpio_bank0,
        &mut pac.RESETS,
    );

    #[cfg(feature = "debug-to-cli")]
    let consumer = defmt_bbq::init().unwrap();

    // GPIO0-1: SDA/SCL: inter-chip com (i2c0)
    // GPIO2: col0
    // GPIO3: RGB data                  (pio0-sm1)
    // GPIO4-9: col 1-6
    // GPIO16-17: SDA/SCL: oled display (pio1)
    // GPIO28, 21, 23, 20, 22: row0-4
    // GPIO25: WS2812 onboard addressable rgb (pio0-sm0)
    // GPIO29: right_nleft: high = right half

    use embedded_hal::digital::blocking::InputPin;
    let pin = pins.gpio29.into_pull_up_input(); // setup pull-up input
    let is_right = pin.is_high().unwrap_or_else(|_| unreachable!()); // Cannot fail
    pin.into_pull_down_disabled(); // reset the pin to its default status.
    IS_RIGHT.store(is_right, Ordering::Relaxed);

    let runtime = nostd_async::Runtime::new();

    let board = BlackBoard {
        usb_state: AtomicU8::new(UsbDeviceState::Default as u8),
        is_main_half: AtomicBool::new(false),
        scanned: RefCell::new(ArrayDeque::new()),
        to_usb: RefCell::new(ArrayDeque::new()),
    };

    let mut timer = Timer::new(pac.TIMER, &mut pac.RESETS);
    let alarm0 = timer.alarm_0().unwrap_or_else(|| unreachable!());
    let usb_bus = UsbBusAllocator::new(UsbBus::new(
        pac.USBCTRL_REGS,
        pac.USBCTRL_DPRAM,
        clocks.usb_clock,
        true,
        &mut pac.RESETS,
    ));

    let theclock = MyClock(&timer);
    let keyboard_hid = UsbHidClassBuilder::new()
        .add_interface(NKROBootKeyboardInterface::default_config(&theclock))
        .build(&usb_bus);

    // This needs to be the last class to be defined.
    #[cfg(feature = "cli")]
    let usb_serial = RefCell::new(SerialPort::new_with_store(
        &usb_bus,
        [0; USB_SERIAL_RX_SZ],
        [0; USB_SERIAL_TX_SZ],
    ));

    let (pio0, pio0sm0, pio0sm1, ..) = pac.PIO0.split(&mut pac.RESETS);
    let (pio1, pio1sm0, ..) = pac.PIO1.split(&mut pac.RESETS);

    let matrix = matrix::Matrix::new(
        (
            pins.gpio2.into_pull_up_input(),
            pins.gpio4.into_pull_up_input(),
            pins.gpio5.into_pull_up_input(),
            pins.gpio6.into_pull_up_input(),
            pins.gpio7.into_pull_up_input(),
            pins.gpio8.into_pull_up_input(),
            pins.gpio9.into_pull_up_input(),
        ),
        (
            pins.gpio28.into_readable_output(),
            pins.gpio21.into_readable_output(),
            pins.gpio23.into_readable_output(),
            pins.gpio20.into_readable_output(),
            pins.gpio22.into_readable_output(),
        ),
    );

    let system_clock_freq = &clocks.system_clock;
    let neopixel = pins.gpio25;
    let led_strip = pins.gpio3;
    let (oled_sda, oled_scl) = (pins.gpio16, pins.gpio17);
    let (resets, i2c, sda, scl) = (pac.RESETS, pac.I2C0, pins.gpio0, pins.gpio1);

    use nostd_async::Task;
    utils_async::init(alarm0);

    let mut inter_board_task = Task::new(inter_board_app(
        &board,
        system_clock_freq,
        i2c,
        sda,
        scl,
        resets,
        &timer,
    ));
    let mut scan_task = Task::new(scan_app(&board, &timer, matrix));
    let mut usb_task = Task::new(usb_app(
        &board,
        &timer,
        &usb_bus,
        keyboard_hid,
        #[cfg(feature = "cli")]
        &usb_serial,
    ));
    #[cfg(feature = "cli")]
    let mut cli_task = Task::new(cli_app(
        &timer,
        &usb_serial,
        #[cfg(feature = "debug-to-cli")]
        consumer,
    ));
    let mut ui_task = Task::new(ui_app(
        &board,
        &timer,
        (pio0, pio0sm0, neopixel, pio0sm1, led_strip),
        (pio1, pio1sm0, oled_sda, oled_scl),
        system_clock_freq,
    ));

    let _inter_board_hndl = inter_board_task.spawn(&runtime);
    let _scan_hndl = scan_task.spawn(&runtime);
    let usb_hndl = usb_task.spawn(&runtime);
    #[cfg(feature = "cli")]
    let _cli_hndl = cli_task.spawn(&runtime);
    let _ui_hndl = ui_task.spawn(&runtime);

    unsafe {
        rp2040_hal::pac::NVIC::unpend(rp2040_hal::pac::Interrupt::TIMER_IRQ_0);
        rp2040_hal::pac::NVIC::unmask(rp2040_hal::pac::Interrupt::TIMER_IRQ_0);
    }

    usb_hndl.join();

    unreachable!("The USB task shall never end");
}

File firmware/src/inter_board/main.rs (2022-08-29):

use embedded_hal_async::i2c::I2c;
use fugit::ExtU32;
use futures::FutureExt;
use rp2040_hal::{pac, Clock};

#[cfg(not(feature = "debug"))]
use crate::defmt;
use crate::{
    inter_board::{ADDRESS, COLUMN_COUNT},
    utils_async, Source,
};

use super::{Error, Pins, INTER_BOARD_FREQ};

#[cfg(feature = "debug")]
use super::EventWrapper;

struct Timeout;
pub struct Main {
    i2c: rp2040_async_i2c::AsyncI2C<pac::I2C0, Pins>,
    attached: bool,
}
#[cfg(feature = "debug")]
impl defmt::Format for Main {
    fn format(&self, fmt: defmt::Formatter) {
        defmt::write!(fmt, "Main {{…}}")
    }
}

impl Main {
    pub fn new(
        i2c_block: pac::I2C0,
        (sda, scl): Pins,
        resets: &mut pac::RESETS,
        system_clock: &rp2040_hal::clocks::SystemClock,
    ) -> Self {
        let mut i2c = rp2040_async_i2c::AsyncI2C::new(
            i2c_block,
            sda,
            scl,
            INTER_BOARD_FREQ,
            resets,
            system_clock.freq(),
        );
        i2c.set_waker_setter(utils_async::waker_setter);
        unsafe {
            rp2040_hal::pac::NVIC::unpend(rp2040_hal::pac::Interrupt::I2C0_IRQ);
            rp2040_hal::pac::NVIC::unmask(rp2040_hal::pac::Interrupt::I2C0_IRQ);
        }
        Main {
            i2c,
            attached: false,
        }
    }

    pub async fn poll(
        &mut self,
        to_usb: &core::cell::RefCell<crate::ToUSBStack>,
        timer: &rp2040_hal::Timer,
        source: Source,
    ) -> Result<(), Error> {
        if !self.attached {
            let mut count = 0u32;
            loop {
                defmt::info!("new main: attempt {}", count);
                let res = futures::select_biased! {
                    res = self.i2c.write(ADDRESS, &[0x80, 0x01]).fuse() => Ok(res),
                    _ = utils_async::wait_for(timer, 1_000.micros()).fuse() => Err(Timeout)
                };
                // try to configure secondary
                break match res {
                    Ok(Ok(_)) => {
                        self.attached = true;
                        Ok(())
                    }
                    // if left side: retry
                    Ok(Err(_)) if count < 5 => {
                        count += 1;
                        let delay = if source == Source::Right {
                            10_000.micros()
                        } else {
                            5_000.micros()
                        };
                        super::utils_async::wait_for(timer, delay).await;
                        continue;
                    }
                    Ok(_) | Err(Timeout) => Err(Error::Timeout),
                };
            }
        } else {
            let mut health = 5;

            let _timestamp = timer.get_counter_low();
            let mut keypresses = [0; 16];
            loop {
                match futures::select_biased! {
                    res = self.i2c.write_read(ADDRESS, &[0x00], &mut keypresses).fuse() => Ok(res),
                    _ = utils_async::wait_for(timer, 5_000.micros()).fuse() => Err(Timeout)
                } {
                    Ok(res) => break res?,
                    Err(Timeout) if health > 0 => health -= 1,
                    Err(Timeout) => return Err(Error::Timeout),
                }
            }

            // scope the borrows
            let cnt = {
                let mut to_usb = to_usb.borrow_mut();
                let before = to_usb.len();
                // we don't really care about errors, that might just be because of events buffer full
                // We don't have recovery procedures anyway
                keypresses
                    .into_iter()
                    .take_while(|&b| b != 0)
                    .map(|evt| {
                        let evt = evt - 1;
                        let (pressed, key) = (evt & 0x80, evt & 0x7F);
                        // there's no concerns for speed here, u8 are already super optimised.
                        let (row, col) = (key / COLUMN_COUNT, key % COLUMN_COUNT);

                        use keyberon::layout::Event;
                        let conv = if pressed == 0 {
                            Event::Release(row, col)
                        } else {
                            Event::Press(row, col)
                        };
                        defmt::info!("Inter: {}", EventWrapper(conv));
                        conv
                    })
                    .try_for_each(|evt| to_usb.push_back((source, evt)))
                    .map_err(|_| Error::QueueFull)?;
                to_usb.len() - before
            };

            // TODO: actually read that from the UI
            let led = 0;
            // TODO: failure here suck as this means we may get the same event twice and we don't want
            // that.
            let mut frame = arrayvec::ArrayVec::<u8, 3>::new();
            if cnt != 0 {
                frame.push(0x81);
                frame.push(cnt as u8);
            } else {
                frame.push(0x82);
            };
            frame.push(led);

            health = 5;
            loop {
                match futures::select_biased! {
                    res = self.i2c.write(ADDRESS, &frame).fuse() => Ok(res),
                    _ = utils_async::wait_for(timer, 7_000.micros()).fuse() => Err(Timeout)
                } {
                    Ok(res) => break res?,
                    Err(Timeout) if health > 0 => health -= 1,
                    Err(Timeout) => return Err(Error::Timeout),
                }
            }

            Ok(())
        }
    }

    pub fn release(self, resets: &mut pac::RESETS) -> (pac::I2C0, Pins) {
        let Main { i2c, .. } = self;
        i2c.free(resets)
    }
}

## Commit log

2022-02-15 update submodules references & fix readme case in main.rs
    [main.rs]
2022-04-17 Initiate work on UI, remove dependency on embassy, use rp2040-async-i2c
2022-08-29 migrate keyberon's HidClass to usbd-human-interface-device
2022-08-29 overhaul features
    Use debug-to-cli or debug-to-probe to enable defmt traces
    Use cli to enable usb-serial peripheral
    debug-to-cli enables cli
2022-08-29 update dependencies and enable rp2040 errata5 support
    [main.rs]
2022-08-29 Add missing read_report.
    If this is not called, the report sent by the host (report led state)
    remains in the usb block's mailbox preventing it from entering suspend.
    [main.rs]
2022-08-29 Make the app actually async and rely on on interrupt for blocking operations.
